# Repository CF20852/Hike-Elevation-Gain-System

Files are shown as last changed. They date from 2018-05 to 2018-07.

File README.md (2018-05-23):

# Hike Elevation Gain System

## :construction: Still! UNDER CONSTRUCTION :construction:
There's just another week's worth of work to do, and there always will be.
## Description
This tool uses a microcomputer connected to a GPS receiver and a barometric pressure sensor to record timestamped hike latitude, longitude, and both GPS and barometric elevation data, and a macro-enabled Excel workbook that processes the recorded data to calculate an accurate elevation gain value for a hike.  The workbook VBA macros can also generate a Keyhole Markup Language (.kml) file that can be used to plot the hike route using mapping software, and calculate the total distance of the hike and the distance from the start to various landmarks along the way.

I developed this tool mainly due to frustration with the wide range of elevation gains reported by various sources, including MapMyHike, Google Maps, Google Earth, and Global Mapper.  Google Maps and Google Earth seemed to report more elevation gain than MapMyHike, and Google Earth and Global Mapper (both of which use, or can be configured to use, the Shuttle Radar Topography Mission [SRTM] terrain elevation data) seemed to be in some agreement.

The tool is a system comprising a recording component and a processing component.  The recording component uses an [Arduino](https://www.arduino.cc/en/Guide/Introduction) (or [Arduino-like](http://wiki.microduinoinc.com/Microduino_Series)) hardware platform that incorporates a GPS receiver such as a u-Blox NEO-6M or NEO-M8N to measure and record GPS time, latitude, longitude, and elevation, and a Bosch BMP180/BMP280 temperature and pressure sensor to measure and record the barometric pressure.  For information on the Arduino platform, visit the [Arduino website](https://www.arduino.cc).  For information on the u-Blox GPS receivers, visit the [u-Blox Positioning Chips and Modules website](https://www.u-blox.com/en/positioning-chips-and-modules).  For information on the Bosch pressure sensors, visit the [Bosch Sensortec website](https://www.bosch-sensortec.com/bst/products/environmental/barometric_pressure_sensors/overview_barometricpressuresensors).

The processing component consists of a macro-enabled Excel workbook that processes the recorded data.  There are four main steps in the elevation data processing:
* Correcting the barometric altimeter data, using altimeter setting data from a local airport.  This is what aircraft pilots use to ensure that they have the correct altitude information for the local area;
* Further correcting the barometric altimeter data, using terrain elevation data, which helps remove any constant bias in the barometric elevation data;
* Filtering (smoothing) and plotting the elevation data; and 
* Computing hike elevation gain/loss statistics.

More specifically, processing the hike elevation data includes the following steps:
* Compute some basic statistics of the hike, which include:
  * Start and end time
  * Average latitude and longitude
* Get the Meteorological Terminal Aviation Routine Weather Report (METAR) data for the airport nearest the hike site from before the beginning of the hike until after the end of the hike, using an [API](https://www.aviationweather.gov/help/webservice?page=metarjson) from [NOAA's Aviation Weather Center](https://aviationweather.gov/metar) that returns data in JSON (JavaScript Object Notation) format.  This gives us the local barometric altimeter setting that aircraft pilots use to set their altimeters to indicate the correct altitude, regardless of the local barometric pressure (within reasonable limits).
* Interpolate the METAR altimeter setting data between METAR sample times for each hike data recording sample time.
* Use the interpolated altimeter setting data to correct the measured barometric-pressure-based elevation data.
* Get the Google Maps elevation data corresponding to the latitude/longitude coordinates, using a [Google Maps API](https://developers.google.com/maps/) that returns data in JSON format.  This gives us (I think) the SRTM elevation data.
* Further correct the recorded barometric elevation data by applying a 1st order correction based on the Google Maps elevation data, to correct any constant bias in the barometric pressure data.  This is done using the Excel Solver add-in to calculate a constant barometric pressure offset value that minimizes the sum of the squared differences between the barometric elevation value and the Google Maps elevation value at each hike data recording sample time.
* Filter the GPS, barometric, and Google Maps elevation data using an [infinite-impulse-response (IIR) filter](https://en.wikipedia.org/wiki/Infinite_impulse_response), the development of which has been facilitated by a [tool](http://www-users.cs.york.ac.uk/~fisher/mkfilter/trad.html) developed by Tony Fisher (who is, unfortunately, deceased).
* Compute and display the hike elevation gain and loss from GPS elevation, barometric elevation, and Google Maps elevation.
* Plot (graph) the data.

My initial findings, based on data from 4-5 hikes, are that the barometric elevation data (once calibrated) are probably more realistic and less "noisy" than the measured GPS elevation data and the Google Maps elevation data.  An additional finding, based on experiments with a counterfeit of a u-Blox NEO-6M receiver, is that some GPS receivers (such as the genuine u-Blox receiver) provide much more accurate results than others (such as the Chinese counterfeit of a u-Blox NEO-6M receiver apparently manufactured by Hangzhou ZhongKe Microelectronics CO., Ltd).

## Installation
### Arduino (like) Code
I've posted three versions of the Arduino (or Arduino-like) code.  These three versions are posted here as Arduino sketchbook (not sketch) folders.  All of them use [William Greiman's SdFat library, which can be obtained at this link](https://github.com/greiman/SdFat).  In addition, they use customized versions of [SlashDevin's NeoGPS library](https://github.com/SlashDevin/NeoGPS), which I placed in the libraries folder inside the Arduino sketchbook folder for each version:
    - A version that runs on a Microduino Core+ with the Microduino GPS, Motion, SD, and USBTTL modules, which requires you to install the Arduino for Microduino Integrated Development Environment (IDE) from [the Microduino download site](https://microduinoinc.com/download/).  This IDE includes libraries for the Microduino Motion (\_06_m_Module_Motion), module, which I use, and GPS module (\_06_m_Module_GPS), which I don't use, except for testing the hardware configuration.  For the GPS receiver, I use SlashDevin's NeoGPS library, with some customization in the header files.  Please refer to the NEO-6M Setup.docx document for explanation of the customization.  The Core+ gives you two hardware serial ports.
    - A version that runs on an Arduino Uno with a shield containing a Chinese counterfeit of a u-Blox NEO-6M GPS receiver, which does not implement the u-Blox protocol, and a microSD card socket, and an [Adafruit BMP280 Barometric Pressure + Temperature Sensor Breakout](https://learn.adafruit.com/adafruit-bmp280-barometric-pressure-plus-temperature-sensor-breakout) that I attached and wired onto the shield, connecting SDA on the BMP280 breakout to A4 (SDA) on the Arduino and SCL on the BMP280 breakout to A5 (SCL) on the Arduino.  For this version, I have used SlashDevin's NeoGPS library with some customization in the header files, and the Adafruit BMP280 library.  I found a Chinese-language protocol specification for the Chinese GPS module labeled as a u-blox NEO-6M at [Hangzhou Zhongke Microelectronics Co., Ltd.](http://www.icofchina.com/d/file/xiazai/2017-05-02/ea0cdd3d81eeebcc657b5dbca80925ee.pdf) and translated it to English (with some expected formatting issues) using an [online document translator](https://www.onlinedoctranslator.com/en/translate-chinese-(simplified)-to-english_zh-CN_en), which worked better than expected.  I put a copy of the translated document in the sketchbook folder for this version.  The Arduino Uno only gives you one hardware serial port, tied to the USB port, so this version uses SlashDevin's NeoSWSerial library to communicate with the GPS module.
    - A version that runs on an Arduino Uno with a [DuinoPeak shield](http://duinopeak.com/index.php?route=product/product&product_id=112) containing a u-Blox NEO-N8M GPS receiver and a microSD card socket, and an [Adafruit BMP280 Barometric Pressure + Temperature Sensor Breakout](https://learn.adafruit.com/adafruit-bmp280-barometric-pressure-plus-temperature-sensor-breakout) that I attached and wired onto the shield, connecting SDA on the BMP280 breakout to A4 (SDA) on the Arduino and SCL on the BMP280 breakout to A5 (SCL) on the Arduino.  I used SlashDevin's NeoGPS library with customized header files and the Adafruit BMP280 library for this version also.
1.  Configure your hardware according to one of the options above.
2.  Download the corresponding sketchbook folder.
3.  In the Arduino IDE, go to File... Preferences... Sketchbook location and set the sketchbook location to the location of the sketchbook folder corresponding to the hardware configuration you chose.  See the notes on Arduino library usage below for an explanation of why I do it this way.
4.  Compile and upload the sketch to your Arduino or Microduino.
#### Some notes on Arduino library usage
When I first started developing the three hardware variants of this project, I put all of the necessary libraries in C:\Users\username\My Documents\Arduino\libraries, where my sketchbook folder was C:\Users\username\My Documents\Arduino.  That was OK for the barometric pressure sensor, because I could use one library for the BMP180 and another library for the BMP280, with no customization required.  But the NeoGPS library is highly configurable via multiple header files for different protocol types (e.g., NMEA vs proprietary), variations on what NMEA sentences different receivers put out, and what information you want out of those sentences (e.g., if you don't need speed and heading, you can configure the library to not parse them, thus saving processing time and memory).  The NeoGPS library has a a src folder containing NMEA sentence processing .h and .cpp files, and subfolder under src called ublox, which contains .h and .cpp files for handling the u-blox proprietary GPS receiver protocol.  In addition, using an Arduino Uno, which only has one hardware serial port, you have a specific GPS serial port configuration, but with the Microduino Core+, you have a second hardware serial port that you can use, which requires a different GPSPort.h configuration in NeoGPS.  So I started out creating different versions of the various NeoGPS header files with different names for the different configurations.  This (IMO) was a really bad idea, because if I update the NeoGPS library, the Arduino library manager replaces the existing library folder with the updated library folder, thus wiping out any custom header files I created.  (Hooray for daily backups!)  Moreover, it starts to get ugly (inelegant) fast.

After some research, I learned that the Arduino IDE looks for libraries in several places (the following is Windows specific):  (1) the libraries folder in your sketchbook, e.g. C:\Users\username\My Documents\Arduino\libraries; (2) in the libraries folder of the Arduino IDE installation folder, e.g. C:\Program Files (x86)\Arduino\libraries; (3) in the folders below C:\Program Files (x86)\Arduino\hardware, e.g., C:\Program Files (x86)\Arduino\hardware\arduino\avr\libraries; and (4) in your sketch folder.  If you want to include a library in one of the first three places, you enclose the appropriate header file name in angle brackets (<>), e.g.,

`#include <SomeLib.h>`,

and if you want to include a library in your sketch (not sketchbook) folder, you enclose the header file name in double quotes, e.g.

`#include "MyLib.h"`.

I'm told that if you use the latter syntax, if the Arduino IDE doesn't find the library source file in your sketch folder, it will look in the places listed above for the angle bracket syntax.

To be able to have several different configurations of the NeoGPS library, as well as other libraries including Adafruit_BMP280_Library or Adafruit_BMP085_Library, NeoSWSerial (if using an Arduino Uno, not needed for a Microduino Core+), PString, and SDFat, the solution I eventually settled on is to have a different sketchbook folder for each configuration, containing a libraries folder and a sketch folder.  I have a copy of the each of the required libraries that are normally stored in the Arduino sketchbook folder in the libraries folder of the hardware-configuration-specific sketchbook folders.  The main disadvantage of this approach (in addition to multiple copies of libraries that you may need to update) is that you have to remember to point the Arduino IDE to the correct sketchbook.  You can easily change the sketchbook folder that the Arduino IDE uses under File... Preferences... Sketchbook location in the Arduino IDE (I'm using version 1.8.5 right now).

Another thing I learned is that if a library has at least one subfolder containing additional source code (.h and/or .cpp) files, all of the source code files must be within a src folder inside the library folder, or the IDE won't find the source code files within the subfolder.  An exception to this src folder requirement may be if the subfolder is named "utility".  See the Arduino IDE 1.5: Library specfication, under the Layout of folders and files heading.  I quote:  

>The source code found in src folder and all its subfolders is compiled and linked in the user's sketch. Only the src folder is added to the include search path (both when compiling the sketch and the library). When the user imports a library into their sketch (from the "Tools > Import Library" menu), an #include statement will be added for all header (.h) files in the src/ directory (but not its subfolders). As a result, these header files form something of a de facto interface to your library; in general, the only header files in the root src/ folder should be those that you want to expose to the user's sketch and plan to maintain compatibility with in future versions of the library. Place internal header files in a subfolder of the src/ folder.

>For backward compatibility with Arduino 1.0.x, the library author may opt to place source code into the root folder, instead of the folder called src. In this case the 1.0 library format is applied and the source code is searched from the library root folder and the utility folder...

I hope this explanation helps someone avoid wasting the amount of time I did in making my project work and look (I hope) at least a bit elegant.

### Excel Workbook
1.  Of course, you'll need Microsoft Excel to use the Excel macro-enabled workbook.  I used Excel 2016.

2.  I was very happy to find an Excel Visual Basic for Applications (VBA) JSON parser at https://github.com/VBA-tools/VBA-JSON.  It's always nice to find some giants who are willing to let you stand on their shoulders.  I just downloaded JsonConverter.bas from [that site](https://github.com/VBA-tools/VBA-JSON) and imported it into my Visual Basic code as a module.

3.  My Excel macro-enabled workbook also uses the Solver Add-in.  If you haven't already enabled it in your copy of Excel, you'll need to do so.  In my version (2016) of Excel, that's done by going to File... Options... Add-ins... Manage Excel Add-ins... Go, and then checking the Solver box and clicking OK.  Depending on which version of Excel you have, your approach may differ.

4.  Download and open the workbook from this page.  When you open the spreadsheet in Excel, you'll probably have to OK enabling macros.

5.  I hike mainly in Arizona, Maryland, Pennsylvania, Virginia, and West Virginia, so those are the states for which I've included airports that report METAR data in the Airports tab of the workbook.  If you live somewhere else, you'll need to download the airports for your area from the [ADDS Station Table](https://www.aviationweather.gov/docs/metar/stations.txt).  Only include the stations that have a "X" in the "M" column of the table (column 63).  Just append them to the bottom of the Airports sheet below the other airports.

## Operation
### Arduino
There's not much to it.  The way it stands right now, if you plug a [well-formatted SD card](https://www.sdcard.org/downloads/formatter_4/) into the recorder, with less than 99 HikeLgxx.csv files (where xx = 0-99) on it, and apply power, it'll create a new HikeLgxx.csv file with the next available number and start recording every 2 seconds as soon as the GPS receiver starts outputting messages.
### Excel Workbook
#### Elevation Gain Calculations
This is a lot more complicated than the Arduino part, given the current state of the "art"...
1.  Ensure that you have an internet connection, because the macros have to retrieve data using the Aviation Weather Center METAR API and the Google Maps elevation data API;
2.  On the Control sheet of the Excel workbook, enter the following data:
    - Your Google Maps API key, which you can obtain from [this website](https://developers.google.com/maps/documentation/elevation/start), in cell B7;
    - Date of the hike, in YYYY-MM-DD or MM/DD/YYYY format, in cell B14.
    - As far as the other cells on the Control sheet are concerned, you should either not mess with them or they will be automagically filled in by the macros.
2.  Open the .csv file recorded by the Microduino or Arduino as an Excel spreadsheet;
3.  Delete everything in the Data sheet of the Excel workbook below the header row, which is row 1 i.e., delete everything in row 2 and below;
4.  Copy the UTC time, latitude and longitude (+/-DD.DDDDD format), GPS elevation (feet), temperature (degrees C), pressure (HPa), baro elevation (feet), number of satellites, HDOP, and VDOP data from the appropriate Hikelgxx.csv file to the Data sheet starting in Row 2, Column 1, i.e. starting in cell A2 of the Data worksheet;
5.  Press \<CTRL>\<p>  to start processing the data.
6.  Look at the results on the Data sheet, primarily in Row 2, Columns U, Y, and AC.  Also look at the two charts, Unfilt Elev and Filt Elev, to get a sense of how the three data sources (GPS elevation, baro elevation, and Google Maps elevation) match up.
#### KML File Generation
This is somewhat simpler than the elevation gain calculations:
1.  On the Control sheet of the Excel workbook, enter the file location at which you want to store your .kml file, should you choose to generate one, in cells B1-B3;
2.  Press \<CTRL>\<k> to generate the .kml file.
#### Distance Calculations
##### Total Hike Distance Calculation
Press \<CTRL>\<d> to calculate the total distance of the hike.
##### Distance to a Waypoint or Landmark
1. Enter the latitude and longitude of the waypoint in cells B27 and C27 respectively;
2. Press \<CTRL>\<q> to calculate the distance.

##  Brief Description of the Excel Workbook
### Control Tab
This is the worksheet on which you enter some parameters related to generating a Keyhole Markup Language (.kml) file, your Google Maps API keyt, the date of the hike, waypoint latitude and longitude if you want to calculate distance to a waypoint.  It's also where certain intermediate results of the elevation processing show up, and where the distances are displayed.
### Data Tab
This is the worksheet onto which you copy and paste the data from the hike log file recorded by the Arduino (like) machine.
### Airports Tab
This is the worksheet that contains the information (most importantly, the latitude and longitude) of any airports from which you want the workbook to retrieve local altimeter setting data.
### METARS Tab
This is a worksheet whose contents are automatically generated by the macros after retrieving the METAR data for the selected airport.
### GM API Rqsts Tab
This is a worksheet whose contents are automatically generated by the macros in the process of requesting elevation data from Google Maps.
### GM Elev Tab
This is a worksheet whose contents are automatically generated by the macros from the elevation data returned by the Google Maps API.
### Unfilt Elev Chart
This is an automatically generated chart showing the unfiltered barometric, GPS, and Google Maps elevation data versus UTC time.
### Filt Elev Chart
This is an automatically generated chart showing the filtered barometric, GPS, and Google Maps elevation data versus UTC time.  The filter is a digital third-order Butterworth IIR filter implemented in a macro.
### Filt Elev v Dist Chart
This is an automatically generated chart showing the filtered barometric, GPS, and Google Maps elevation data versus distance from the beginning of the hike.  The filter is a digital third-order Butterworth IIR filter implemented in a macro.

## Some initial results
This figure shows the GPS altitude (blue) and barometric cabin pressure (orange) of a flight from Phoenix, Arizona to Baltimore, Maryland, just plotted straight from the recorded .csv file:

PHX-BWI

This figure shows the GPS altitude and corrected barometric elevation measured at a stationary location next to a sliding glass door in my basement, processed through the Excel workbook:

Basement

This figure shows the filtered GPS, barometric, and Google Maps elevations with respect to distance from the beginning of a hike from where the Appalachian Trail crosses State Rte 94 south of Mount Holly Springs, Pennsylvania to Boiling Springs, Pennsylvania.  This used a u-blox NEO-M8N GNSS receiver, which I think I accidently left in AIR_4G dynamics mode, instead of PEDESTRIAN mode:

AT Hike 20 May 2018

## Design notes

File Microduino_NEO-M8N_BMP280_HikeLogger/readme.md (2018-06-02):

This version is for a Microduino with an Arduino Uno adapter including the Core+ module and the DuinoPeak NEO-M8N + SD shield with an Adafruit BMP280 breakout attached.

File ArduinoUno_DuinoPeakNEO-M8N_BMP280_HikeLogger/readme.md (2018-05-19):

This version is for the Arduino Uno with a shield containing a u-blox NEO-M8N, a Bosch BMP-280, and a microSD card socket.

If you buy a NEO-M8N/microSD shield from DuinoPeak, the NEO-M8N may come with firmware version 2.01.  If so, you may have to upgrade the firmware to version 3.01 for this configuration to work properly.  (Try it without upgrading the NEO-M8N firmware first.)  You can upgrade the firmware using the u-blox u-connect software, which I obtained from https://www.u-blox.com/en/evaluation-software-and-tools for my Windows 10 laptop.  Use the u-blox 8/M8 Firmware v 3.01 - ONLY for Standard Precision NGSS products, which I obtained at https://www.u-blox.com/sites/default/files/UBX_M8_301_SPG.911f2b77b649eb90f4be14ce56717b49.bin .

One of the benefits of upgrading is that you could configure the NEO-M8N to simultaneously use GPS, Galileo, and GLONASS or Galileo, GLONASS, and BeiDou signals.  See section 32.11.11 of the u-blox 8/ u-blox M8 Receiver Description Including Protocol Specification document (Document number UBX-13003221) to learn how to compose the necessary u-blox command.  I haven't included that in this sketch, due to the fact that running on an Arduino Uno, the sketch already consumes perilous amounts of flash and RAM.  The default configuration of the u-blox 8/u-blox M8 Standard Precision GNSS modules using both firmware versions 2.01 and 3.01 is to use GPS, SBAS, QZSS, and GLONASS signals.  See Appendix B.6, GNSS System Settings, of Document number UBX-13003221.  See Appendix A of that document for how u-blox numbers the GNSS system types 0-6, corresponding to GPS, SBAS, Galileo, BeiDou, IMES, QZSS, and GLONASS respectively.

In order to connect u-center running on my laptop to the NEO-M8N on the DuinoPeak shield, I used an Arduino Uno and configured the DuinoPeak shield to communicate with the Arduino Uno using D0 and D1, rather than D2 and D3.  I found trying to relay the serial port through the Arduino Uno software to be too unreliable.  I wrote a small sketch to configure D0 and D1 as inputs for this purpose, using the Arduino pinMode() function.

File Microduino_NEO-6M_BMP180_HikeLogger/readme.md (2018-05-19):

This version is for a Microduino board stack including the Core+, USBTTL, SD, GPS, and Motion modules.  The GPS module includes a genuine u-blox NEO-6M and the Motion module includes a Bosch BMP-180.

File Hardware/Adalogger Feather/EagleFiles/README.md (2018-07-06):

Autodesk Eagle 9.0.1 (free version) files for a Feather daughterboard for an Adafruit Feather M0 Adalogger.

There is at least one error in this design:  the GPIOSDA and GPIOSCL lines coming from the Adafruit Adalogger board do not have pullup resistors, and because these lines are open-drain, the daughterboard must provide the pullup resistors.

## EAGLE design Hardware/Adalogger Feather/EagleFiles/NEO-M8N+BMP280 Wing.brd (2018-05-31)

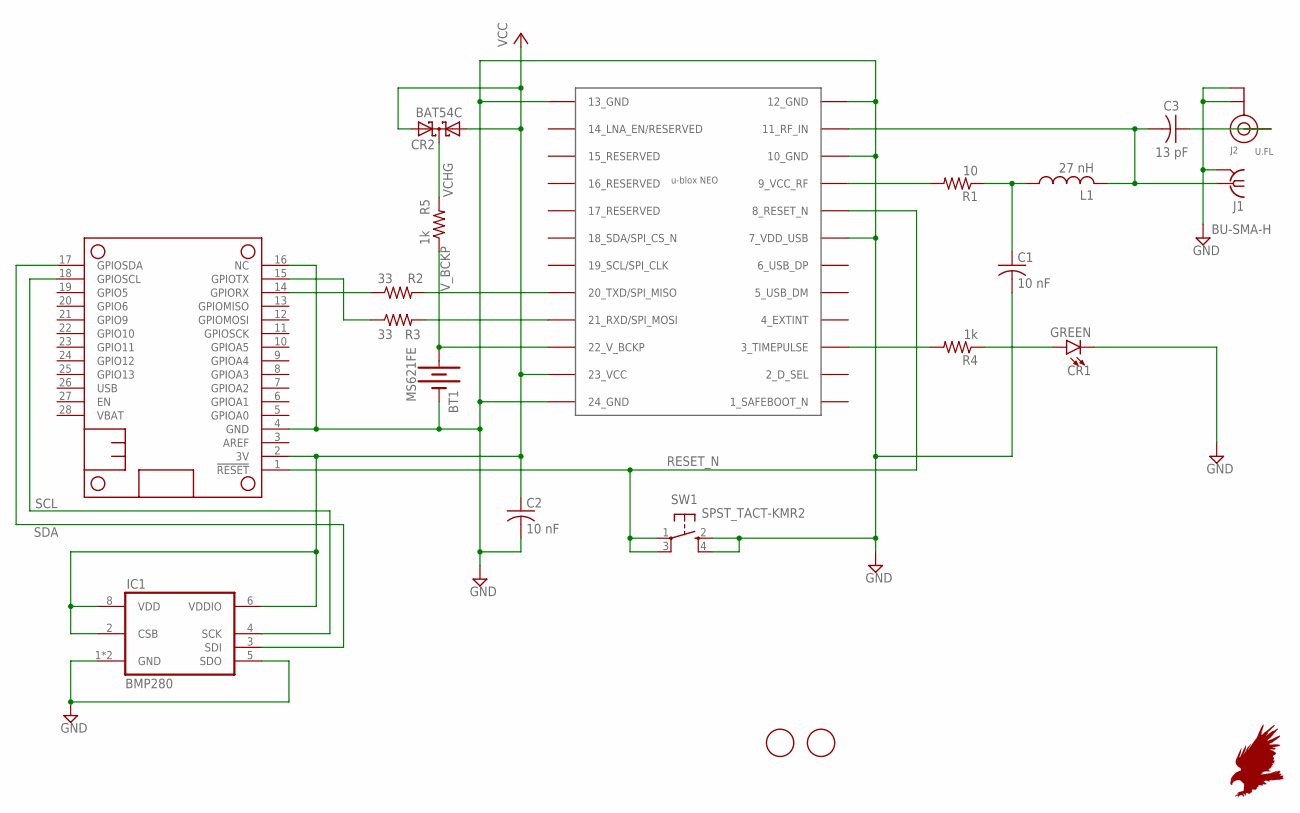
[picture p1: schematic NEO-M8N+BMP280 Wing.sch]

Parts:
BT1: MS621FE; BATTCON-6.8MM
C1, C2: 10 nF; C0402
C3: 13 pF; C0402
CR1: GREEN; LED-0603
CR2: BAT54C; SOT23
FID1, FID2: FIDUCIAL; FIDUCIAL_1MM
IC1: BMP280
J1: BU-SMA-H
J2: U.FL
L1: 27 nH; L0402
MS1: FEATHERWING
R1: 10; R0805
R2, R3: 33; R0805
R4, R5: 1k; R0805
SW1: SPST_TACT-KMR2; KMR2
U$2: NEO-M8

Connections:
FEATHER_RXD: MS1.14 (GPIORX), R2.1
FEATHER_TXD: MS1.15 (GPIOTX), R3.1
GND: BT1.-, C1.2, C2.2, CR1.C, IC1.1 (GND), IC1.5 (SDO), IC1.7 (GND), J1.2, J1.3 (2), J1.4 (2), J1.5 (2), J2.1 (GND), J2.2 (GND), MS1.4 (GND), MS1.16 (NC), SW1.2 (S), SW1.4 (S1), U$2.7 (7_VDD_USB), U$2.10 (10_GND), U$2.12 (12_GND), U$2.13 (13_GND), U$2.24 (24_GND)
GPS_RXD: R3.2, U$2.21 (21_RXD/SPI_MOSI)
GPS_TXD: R2.2, U$2.20 (20_TXD/SPI_MISO)
J2_RF: C3.1, J2.3 (SIGNAL)
LED_ANODE: CR1.A, R4.1
LNA_BIAS: C1.1, L1.P$1 (1), R1.1
RESET_N: MS1.1 (!RESET), SW1.1, SW1.3 (P1), U$2.8 (8_RESET_N)
RF_IN: C3.2, J1.1, L1.P$2 (2), U$2.11 (11_RF_IN)
SCL: IC1.4 (SCK), MS1.18 (GPIOSCL)
SDA: IC1.3 (SDI), MS1.17 (GPIOSDA)
TP: R4.2, U$2.3 (3_TIMEPULSE)
VCC: C2.1, CR2.1 (A1), CR2.2 (A2), IC1.2 (CSB), IC1.6 (VDDIO), IC1.8 (VDD), MS1.2 (3V), U$2.23 (23_VCC)
VCC_RF: R1.2, U$2.9 (9_VCC_RF)
VCHG: CR2.3 (CC), R5.2
V_BCKP: BT1.+, R5.1, U$2.22 (22_V_BCKP)

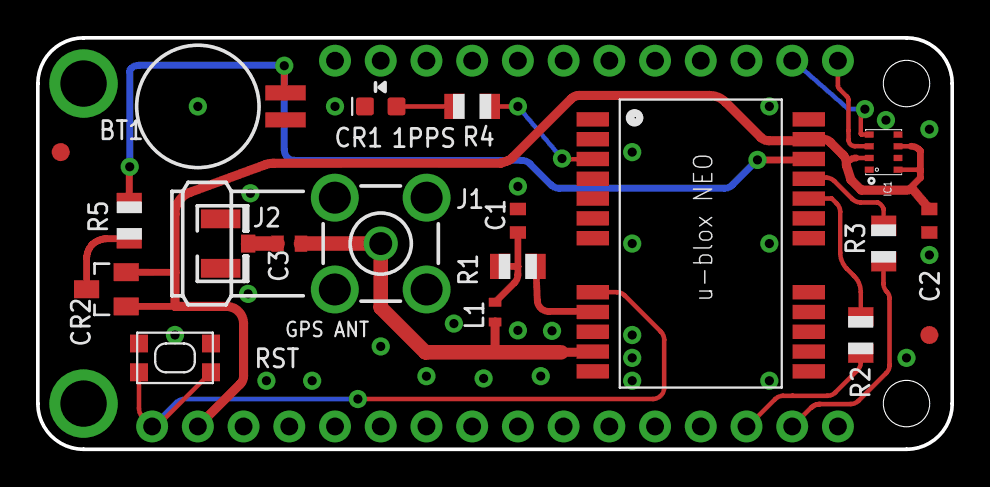
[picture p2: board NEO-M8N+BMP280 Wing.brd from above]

Board: 2 copper layers, 50.8 x 22.9 mm, 20 parts (0 on the bottom side), 17 nets.

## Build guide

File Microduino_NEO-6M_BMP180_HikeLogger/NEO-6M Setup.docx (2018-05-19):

The following is from Appendix A of the u-Blox 6 Receiver Description including Protocol Specification. Default configuration parameters highlighted in yellow should be changed for the hike logging application. Changes are explained at the end of this document.

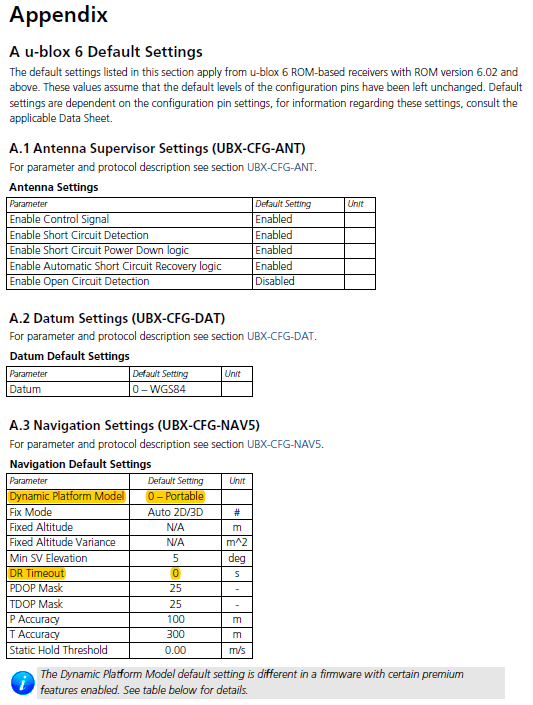
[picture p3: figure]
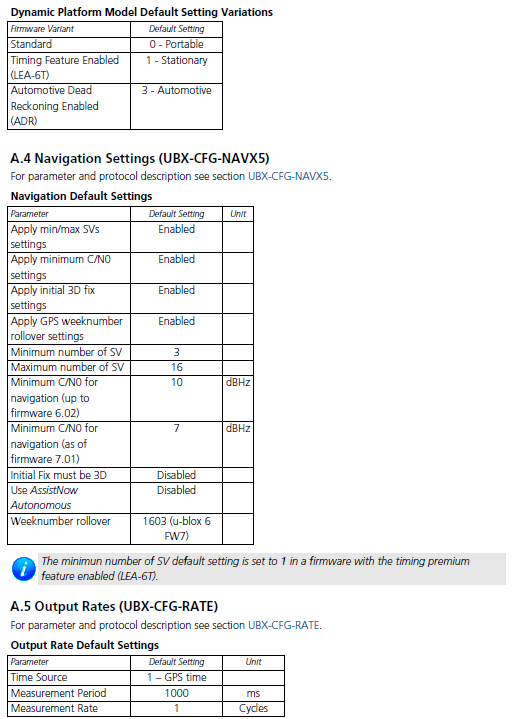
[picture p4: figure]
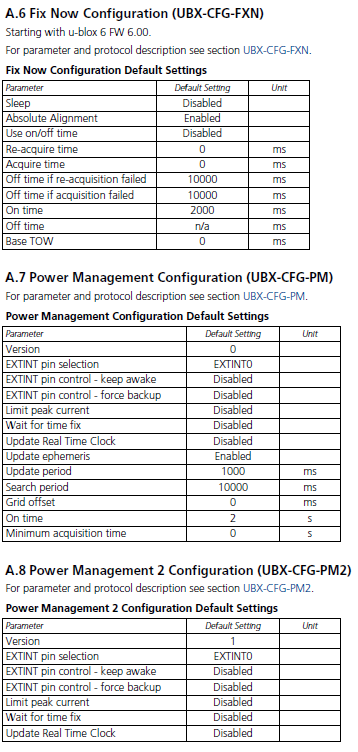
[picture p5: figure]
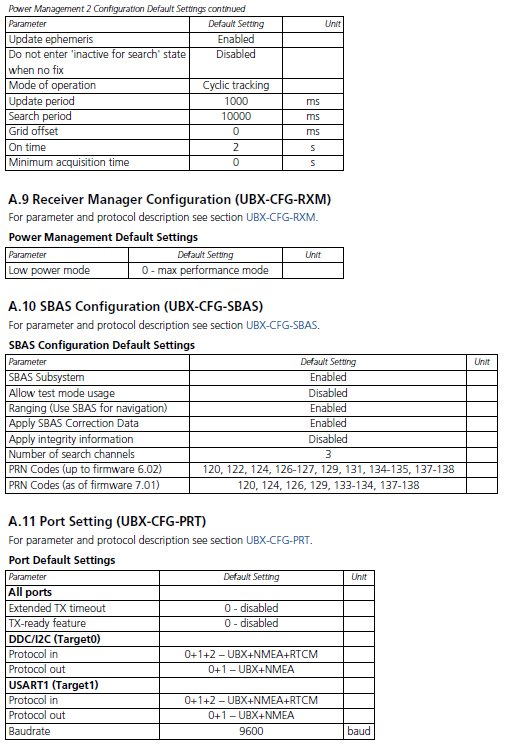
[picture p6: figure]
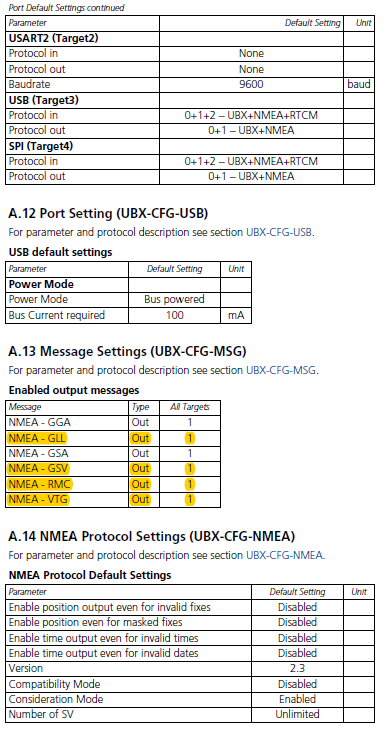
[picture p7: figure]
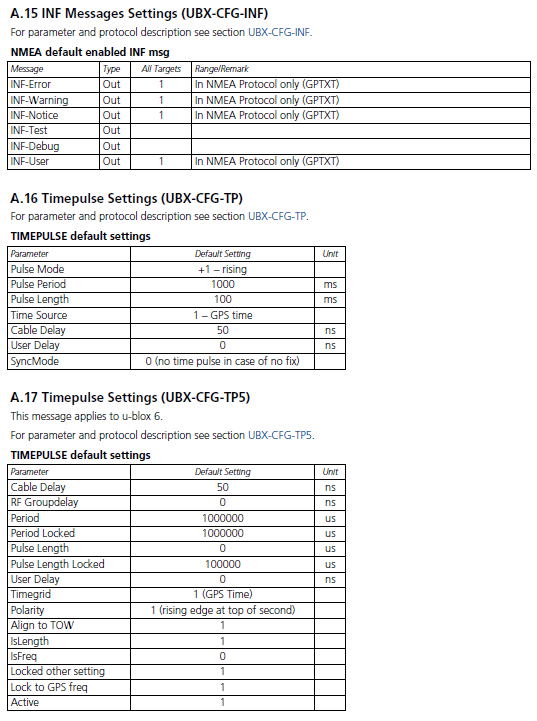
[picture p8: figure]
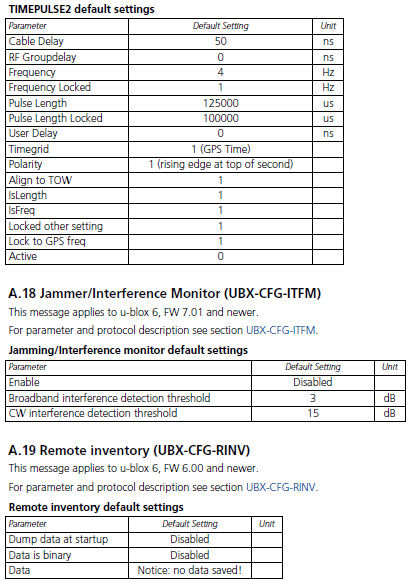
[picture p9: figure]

Default Navigation Settings (UBX-CFG-NAV5)

For parameter and protocol description see section UBX-CFG-NAV5.
Parameter | Default Setting | Desired Setting | Unit
Dynamic Platform Model | 0 – Portable | 3 -- Pedestrian
Fix Mode | Auto 2D/3D | Auto 2D/3D | #
Fixed Altitude | N/A | N/A | m
Fixed Altitude Variance | N/A | N/A | m^2
Min SV Elevation | 5 | 5 | deg
DR Timeout | 0 | 30 | s
PDOP Mask | 25 | 25 | -
TDOP Mask | 25 | 25 | -
P Accuracy | 100 | 100 | m
T Accuracy | 300 | 300 | m
Static Hold Threshold | 0 | 0 | m/s

Code to change NAV5 settings using NeoGPS library by SlashDevin:

Brute force method:

ublox::cfg_nav5_t setNav;

setNav.apply_word = 0x0009; // only change dynModel and drLimit

setNav.dyn_model = ublox::UBX_DYN_MODEL_PEDESTRIAN;

setNav.fix_mode = ublox::UBX_POS_FIX_AUTO;

setNav.fixed_alt = 0; // m

setNav.fixed_alt_variance = 10000; // 10000 * m^2

setNav.min_elev = 5; // degrees

setNav.dr_limit = 20; // s

setNav.pos_dop_mask = 250; // 10 * DOP

setNav.time_dop_mask = 250; // 10 * DOP

setNav.pos_acc_mask = 100; // m

setNav.time_acc_mask = 300; // s (although spec says "m")

setNav.static_hold_thr = 0; // cm/s

setNav.dgps_timeout = 0; // s

More readable and precise method:

// THIS COMMAND SETS THE NAV5 MODES using the more readable and precise method

ublox::cfg_nav5_t navCfg;

// set the mask bit indicating we're changing the dynamic model...

navCfg.apply.dyn_model = true

// and change the model to Pedestrian, for hikers

// note that UBX_DYN_MODEL_AIR_4G was tested on an airline flight (PHX-BWI) and works

navCfg.dyn_model = ublox::UBX_DYN_MODEL_PEDESTRIAN;

// set the mask bit indicating we're changing the ded(uced) reckoning limit...

// and change the limit to 20 s, for hikers whose signals are sometimes blocked

navCfg.apply.dr_limit = true;

navCfg.dr_limit = 20;

while (!gps.send( navCfg )) {

DEBUG_PORT.print( '.' );

delay( 500 );

}

Message Settings (UBX-CFG-MSG)

For parameter and protocol description see section UBX-CFG-MSG.
Message | Default Targets & Rate | Desired Targets & Rate
NMEA - GGA | All, 1 | UART 1, 1
NMEA - GLL | All, 1 | None
NMEA - GSA | All, 1 | UART 1, 1
NMEA - GSV | All, 1 | None
NMEA - RMC | All, 1 | None
NMEA - VTG | All, 1 | None

Code to change message settings using NeoGPS library by SlashDevin:

NMEAGPS::nmea_msg_t msgType[6] =

{NMEAGPS::NMEA_GGA, NMEAGPS::NMEA_GLL, NMEAGPS::NMEA_GSA, NMEAGPS::NMEA_GSV, NMEAGPS::NMEA_RMC, NMEAGPS::NMEA_VTG};

uint8_t rate[6] = {1, 0, 1, 0, 0, 0};

int maxI = (sizeof(msgType)/sizeof(NMEAGPS::nmea_msg_t));

for (int i = 0; i < maxI; i++) {

Serial.print(F("Setting message type "));

Serial.print(msgType[i]);

Serial.print(F(" to rate "));

Serial.println(rate[i]);

while (!ublox::configNMEA(gps, msgType[i], rate[i])) {

Serial.print( '.' );

delay( 500 );

}

Serial.println();

}

Also, in NMEAGPS_cfg.h of SlashDevin’s NeoGPS library, make sure NMEAGPS_PARSE_SATELLITES, NMEAGPS_PARSE_GGA, NMEAGPS_PARSE_GSA, NMEAGPS_COMMA_NEEDED, and LAST_SENTENCE_IN_INTERVAL NMEAGPS::NMEA_GSA are #defined, consistent with the message types enabled by the code above.

In GPSfix_cfg.h of SlashDevin’s NeoGPS library, comment/uncomment the #defines as shown below:

//#define GPS_FIX_DATE

#define GPS_FIX_TIME

#define GPS_FIX_LOCATION

//#define GPS_FIX_LOCATION_DMS

#define GPS_FIX_ALTITUDE

//define GPS_FIX_SPEED

//#define GPS_FIX_VELNED

//define GPS_FIX_HEADING

#define GPS_FIX_SATELLITES

#define GPS_FIX_HDOP

#define GPS_FIX_VDOP

//#define GPS_FIX_PDOP

//#define GPS_FIX_LAT_ERR

//#define GPS_FIX_LON_ERR

//#define GPS_FIX_ALT_ERR

//#define GPS_FIX_GEOID_HEIGHT

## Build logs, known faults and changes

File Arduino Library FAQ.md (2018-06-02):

# Arduino Library FAQ
## Where does the Arduino IDE look for libraries?
The Arduino IDE looks for libraries in several places (the following is Windows specific):  (1) the libraries folder in your sketchbook, e.g. C:\Users\username\My Documents\Arduino\libraries; (2) in the libraries folder of the Arduino IDE installation folder, e.g. C:\Program Files (x86)\Arduino\libraries; (3) in the folders below C:\Program Files (x86)\Arduino\hardware, e.g., C:\Program Files (x86)\Arduino\hardware\arduino\avr\libraries; and (4) in your sketch folder.  If you want to include a library in one of the first three places, you *should* enclose the appropriate header file name in angle brackets (<>), e.g.,

`#include <SomeLib.h>`, 

and if you want to include a library in your sketch (not sketchbook) folder, or in a library folder inside a src folder in your sketch folder, you *must* enclose the header file name in double quotes, e.g.

`#include "MyLib.h"` or<br>
`#include "src/MyLib1/src/MyLib1.h"`.

Note that if you use the double-quote syntax, the Arduino IDE will also look in the places listed above for the angle brackets syntax if it doesn't find the source files in your sketch folder.

## What do I do if I need multiple versions of the same library, or a customized version?
First, some cautionary advice:  The Arduino IDE will generate advisory (not error, or warning) messages if it finds multiple, identically-named copies of the same header files in the locations in which it searches for libraries.  This should tell you to think carefully about what you've done.  

Moreover, and more importantly, if you update the library using the Arduino Library Manager, the new library folder will replace the existing library folder with the same name in your sketchbook folder.  If you update a library using the Arduino Library Manager while the Arduino IDE sketchbook folder is set to your specific sketchbook location, the library in your specific sketchbook location will be overwritten. In the interest of caution and at the cost of repetition, I'll re-emphasize this point below.

Four options you can consider are:

1.  Under this option, your libraries are assumed to be in the default library location, which under Windows, is C:\Users\username\My Documents\Arduino\libraries.  If there are a small number of source code (i.e., .h and .cpp) files in the library, you can assign different file names to different versions of the source code files.  *If you choose this option, be sure to back up your custom source code files if you decide to update the library.  If you update a library using the Arduino Library Manager while the Arduino IDE sketchbook folder is set to the default sketchbook location, the library in the default sketchbook location will be overwritten.*
2.  If there are many source code files in the library, it might be better to place your sketch and the custom libraries it requires, along with any other libraries your sketch requires that are normally located in the default sketchbook folder, in a separate sketchbook folder.  You can tell the Arduino IDE to use that sketchbook folder by going to File... Preferences... Sketchbook location in the Arduino IDE and setting the sketchbook location to the appropriate folder.  You should maintain the structure of the original library folder(s), including maintaining the source code in a subfolder of your library folder(s) called "src".  You may also need to tailor the example sketches for your customized libraries according to your own needs, in which case the place to do it is within the examples folder of your library folder(s).  *Be aware that if you update a library using the Arduino Library Manager while the Arduino IDE sketchbook folder is set to your specific sketchbook location, the library in your specific sketchbook location will be overwritten.*  The sketchbook structure should end up looking something like this, assuming you have a folder in the root directory of your C: drive called Arduino Sketchbooks:
<br>C:
<br>&emsp;|_Arduino Sketchbooks
<br>&emsp;&emsp;|_MySketchbook1
<br>&emsp;&emsp;&emsp;|_MySketch1
<br>&emsp;&emsp;&emsp;&emsp;|_MySketch1.ino
<br>&emsp;&emsp;&emsp;&emsp;|_libraries
<br>&emsp;&emsp;&emsp;&emsp;&emsp;|_MyLibrary1
<br>&emsp;&emsp;&emsp;&emsp;&emsp;&emsp;|_src
<br>&emsp;&emsp;&emsp;&emsp;&emsp;&emsp;&emsp;|_lib1.h
<br>&emsp;&emsp;&emsp;&emsp;&emsp;&emsp;&emsp;|_lib1.cpp
<br>&emsp;&emsp;&emsp;&emsp;&emsp;|_MyLibrary2
<br>&emsp;&emsp;&emsp;&emsp;&emsp;&emsp;|_src
<br>&emsp;&emsp;&emsp;&emsp;&emsp;&emsp;&emsp;|_lib2.h
<br>&emsp;&emsp;&emsp;&emsp;&emsp;&emsp;&emsp;|_lib2.cpp

The next two approaches were suggested by per1234:

3.  Rather than dealing with multiple sketchbooks, another way to handle the different versions of a library is to bundle a modified version of that library with each sketch. So the sketch directory tree would look like this:
<br>C:
<br>&emsp;|_Arduino Sketchbooks
<br>&emsp;&emsp;|_MySketch1
<br>&emsp;&emsp;&emsp;|_MySketch1.ino
<br>&emsp;&emsp;&emsp;|_src
<br>&emsp;&emsp;&emsp;&emsp;|_MyLibrary1
<br>&emsp;&emsp;&emsp;&emsp;&emsp;|_src
<br>&emsp;&emsp;&emsp;&emsp;&emsp;&emsp;|_lib1.h
<br>&emsp;&emsp;&emsp;&emsp;&emsp;&emsp;|_lib1.cpp
<br>&emsp;&emsp;&emsp;&emsp;|_MyLibrary2
<br>&emsp;&emsp;&emsp;&emsp;&emsp;|_src
<br>&emsp;&emsp;&emsp;&emsp;&emsp;&emsp;|_lib2.h
<br>&emsp;&emsp;&emsp;&emsp;&emsp;&emsp;|_lib2.cpp

And the sketch includes the libraries like this:
    
    #include "src/MyLibrary1/src/lib1.h"
    #include "src/MyLibrary2/src/lib2.h"

Then the sketches can all share the other libraries that don't require any modifications.

4.  Another option is to make each version of each library for which you need a hardware-specific variation a separate library in the main libraries folder (e.g., C:\Users\username\My Documents\Arduino\libraries) with a separate name. If you change the folder name then there is no problem with Library Manager updates overwriting the modified library. If you change the header file name then you will be able to control which library is included by your code. The advantage of this is that it would permit you to merge all of your sketch variations into one. The you can have a configuration macro at the top of the sketch:

`// Uncomment one of the following lines to configure the sketch:`<br>
`// #define HARDWARE_CONFIGURATION_1`<br>
`// #define HARDWARE_CONFIGURATION_2`<br>
`// #define HARDWARE_CONFIGURATION_3`<br>

Then anywhere there is code that differs between the versions:

    #if defined(HARDWARE_CONFIGURATION_1)
    // HARDWARE_CONFIGURATION_1 specific code here
    #elif defined(HARDWARE_CONFIGURATION_2)
    // HARDWARE_CONFIGURATION_2 specific code here
    #else
    // HARDWARE_CONFIGURATION_3 specific code here
    #endif

This is a good option if you have a lot of code that's shared between the various n sketches, otherwise when you want to make a change it get's really tiresome having to do it nX every time. The disadvantage is all that preprocessor code gets pretty messy.

## What do I do if I need to create my own library?
Even if you don't plan to publish your library for use by others, you should follow the [Arduino Library Specification](https://github.com/arduino/Arduino/wiki/Arduino-IDE-1.5:-Library-specification).  If you aren't going to publish your library, you don't need the library.properties file or the keywords.txt file, nor do you need to have an examples folder or an extras folder.

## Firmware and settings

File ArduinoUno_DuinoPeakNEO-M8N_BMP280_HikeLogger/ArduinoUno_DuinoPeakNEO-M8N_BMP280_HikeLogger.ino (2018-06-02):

/*
  SD card datalogger

  This example shows how to log data from a u-Blox NEO-6M GPS receiver and BMP280 barometric altimeter to an SD card.

  created  24 Nov 2010
  modified 9 Apr 2012
  by Tom Igoe

  adapted for GPS and BMP180 14-30 Apr 2018
  by Chip Fleming

  This code is developed for the Wanderbirds hiking club.
*/

#define recordingInterval 2  //seconds between successive samples

//#define SERIALPORT
#undef SERIALPORT

#include <PString.h>

char buffer[80];
PString dataString(buffer, sizeof(buffer));

// BEGIN SD CARD SECTION *****************************************************************************
#include <SPI.h>
#include "SdFat.h"

// SD chip select pin.  Be sure to disable any other SPI devices such as Enet.
const uint8_t chipSelect = 8;

// Log file base name.  Must be six characters or less.
#define FILE_BASE_NAME "HikeLg"

// File system object.
SdFat sd;

// Log file.
SdFile file;

#define error(msg) sd.errorHalt(F(msg))
// END SD CARD SECTION *******************************************************************************

// BEGIN GPS SECTION *********************************************************************************
//In NMEAGPS_cfg.h of SlashDevin’s NeoGPS library, make sure NMEAGPS_PARSE_SATELLITES, NMEAGPS_PARSE_GGA,
//NMEAGPS_PARSE_GSA, NMEAGPS_COMMA_NEEDED, and LAST_SENTENCE_IN_INTERVAL NMEAGPS::NMEA_TXT are #defined.
//The other NMEAGPS_PARSE_XXX should not be defined, because those messages sent by the NEO-M8N
//do not provide any information that we need and GGA and GSA do not provide.

//In GPSfix_cfg.h of SlashDevin’s NeoGPS library, #define some parameters and comment out the definitions of others, as follows:
//#define GPS_FIX_DATE
//#define GPS_FIX_TIME
//#define GPS_FIX_LOCATION
////#define GPS_FIX_LOCATION_DMS
//#define GPS_FIX_ALTITUDE
////define GPS_FIX_SPEED
////#define GPS_FIX_VELNED
////define GPS_FIX_HEADING
//#define GPS_FIX_SATELLITES
//#define GPS_FIX_HDOP
//#define GPS_FIX_VDOP
////#define GPS_FIX_PDOP
////#define GPS_FIX_LAT_ERR
////#define GPS_FIX_LON_ERR
////#define GPS_FIX_ALT_ERR
////#define GPS_FIX_GEOID_HEIGHT

#include <NMEAGPS.h>
#include <ublox/ubxGPS.h>

#include <GPSport.h>
#include <Streamers.h>

static ubloxGPS gps( &gpsPort );

static NMEAGPS  nmeaGPS; // This parses the GPS characters
gps_fix  fix; // This holds on to the latest values

// END GPS SECTION ***********************************************************************************

// BEGIN BMP280 SECTION ******************************************************************************
#include <Wire.h>
#include "Adafruit_BMP280.h"

Adafruit_BMP280 bmp;
// END BMP280 SECTION ********************************************************************************

void sendUBX( const unsigned char *progmemBytes, size_t len )
//This sends a u-blox-formatted command to the NEO-M8N GPS module, and computes and appends the checksum.
{
  //write the SYNC word
  gpsPort.write( 0xB5 ); // SYNC1
  gpsPort.write( 0x62 ); // SYNC2

  //write the payload, which is in program memory and update the checksum
  uint8_t a = 0, b = 0;
  while (len-- > 0) {
    uint8_t c = pgm_read_byte( progmemBytes++ );
    a += c;
    b += a;
    gpsPort.write( c );
  }

  //write the checksum
  gpsPort.write( a ); // CHECKSUM A
  gpsPort.write( b ); // CHECKSUM B

} // sendUBX

const unsigned char ubxSetUART138400[] PROGMEM =
{ 0x06, 0x00, 0x14, 0x00, 0x01, 0x00, 0x00, 0x00, 0xC0, 0x08, 0x00, 0x00, 0x00, 0x96, 0x00, 0x00, 0x07, 0x00, 0x03, 0x00, 0x00, 0x00, 0x00, 0x00 };

void setup() {
  // Open serial communications and wait for port to open:
  DEBUG_PORT.begin(115200);
  while (!Serial)
    ;
  DEBUG_PORT.println(F("Starting up SD card, NEO-M8N, and BMP280....."));

#if defined (SERIALPORT)
  DEBUG_PORT.println(F("Initializing log file name and SD card..."));
#endif
  // BEGIN SD CARD SECTION *****************************************************************************
  // set up file name
  const uint8_t BASE_NAME_SIZE = sizeof(FILE_BASE_NAME) - 1;
  char fileName[13] = FILE_BASE_NAME "00.csv";

  // Initialize at the highest speed supported by the board that is
  // not over 50 MHz. Try a lower speed if SPI errors occur.
  if (!sd.begin(chipSelect, SD_SCK_MHZ(50))) {
    sd.initErrorHalt();
  }

  // Find an unused file name.
  if (BASE_NAME_SIZE > 6) {
    error("FILE_BASE_NAME too long");
  }
  while (sd.exists(fileName)) {
    if (fileName[BASE_NAME_SIZE + 1] != '9') {
      fileName[BASE_NAME_SIZE + 1]++;
    } else if (fileName[BASE_NAME_SIZE] != '9') {
      fileName[BASE_NAME_SIZE + 1] = '0';
      fileName[BASE_NAME_SIZE]++;
    } else {
      error("Can't create file name");
    }
  }
  if (!file.open(fileName, O_CREAT | O_WRITE | O_EXCL)) {
    error("file.open");
  }
  else {
    DEBUG_PORT.print(fileName);
    DEBUG_PORT.println(F(" opened OK"));
  }
  // END SD CARD SECTION *******************************************************************************

  // BEGIN GPS SECTION *********************************************************************************
  //start the GPS module port at 9600 bps, which is the default for the u-blox NEO-M8N
  gpsPort.begin(9600);
  delay(1000);

  //tell the NEO-M8N to switch to 38.4 kbps
  sendUBX( ubxSetUART138400, sizeof(ubxSetUART138400) );
  delay(1000);

  //restart the Arduino GPS port at 38.4 kbps
  gpsPort.begin(38400);

  //Turn on NMEA messages GxGGA, GxGSA, GxRMC (which we only need for the date, once) and turn everything else off
  NMEAGPS::nmea_msg_t msgType[6] =
  {NMEAGPS::NMEA_GGA, NMEAGPS::NMEA_GLL, NMEAGPS::NMEA_GSA, NMEAGPS::NMEA_GSV, NMEAGPS::NMEA_RMC, NMEAGPS::NMEA_VTG};
  uint8_t rate[6] = {1, 0, 1, 0, 1, 0};

  int maxI = (sizeof(msgType) / sizeof(NMEAGPS::nmea_msg_t));

  for (int i = 0; i < maxI; i++) {
    DEBUG_PORT.print(F("Setting message type "));
    DEBUG_PORT.print(msgType[i]);
    DEBUG_PORT.print(F(" to rate "));
    DEBUG_PORT.print(rate[i]);
    while (!ublox::configNMEA(gps, msgType[i], rate[i])) {
      DEBUG_PORT.print( '.' );
      delay( 500 );
    }
    DEBUG_PORT.println();
  }

  DEBUG_PORT.println("Completed setting the Msg Mode!");
  DEBUG_PORT.println();


  //  THIS COMMAND SETS THE NAV5 MODES using the more readable and precise method
  ublox::cfg_nav5_t navCfg;
  navCfg.apply.dyn_model = true;                       // set the mask bit indicating we're changing the dynamic model...
  navCfg.dyn_model = ublox::UBX_DYN_MODEL_PEDESTRIAN;  //and change the model to Pedestrian, for hikers
  //
  //  // the following two lines should be commented out for the NEO-M8N, for which the ded(uced) reckoning mode is reserved
  //  navCfg.apply.dr_limit = true;                        // set the mask bit indicating we're changing the ded reckoning limit...
  //  navCfg.dr_limit = 20;                                //and change the limit to 20 s, for hikers whose signals are sometimes blocked
  //
  DEBUG_PORT.print( F("Setting uBlox nav mode") );
  while (!gps.send( navCfg )) {
    DEBUG_PORT.print( '.' );
    delay( 500 );
  }
  DEBUG_PORT.println();
  DEBUG_PORT.println("Completed setting the Nav Mode!");
  DEBUG_PORT.println();
  //

  // END GPS SECTION ***********************************************************************************

  // BEGIN BMP280 SECTION ******************************************************************************
  //see if we can start the BMP280
  if (!bmp.begin()) {
    DEBUG_PORT.println(F("Could not find a valid BMP280 sensor, check wiring!"));
  }
  else {
    DEBUG_PORT.println(F("Found a BMP280 sensor, setup is complete."));
  }
  // END BMP280 SECTION ********************************************************************************
}  // end of setup()

uint8_t lastGPSSeconds = 0;
uint32_t timer = millis();
float BMP280Temperature, BMP280Pressure, BMP280Altitude;
bool fileDateSet = false;

void loop() {

  BMP280Temperature = 0;
  BMP280Pressure = 0;
  BMP280Altitude = 0;

  // read data from the GPS in the 'main loop'
  while (nmeaGPS.available( gpsPort )) {
    fix = nmeaGPS.read();
    //DEBUG_PORT.print(".");
  }

  // if the inter-sample interval has elapsed, (optionally) display and record the GPS time,
  //
  if ((fix.dateTime.seconds % recordingInterval == 0) && (fix.dateTime.seconds != lastGPSSeconds) && (fix.latitude() != 0.0)) {
    lastGPSSeconds = fix.dateTime.seconds;

    // if we have valid GPS date and time and we haven't set the file timestamp, do so now
    if ( (!fileDateSet) && (fix.valid.date) && (fix.valid.time) ) {
      if (!file.timestamp(T_CREATE | T_WRITE | T_ACCESS, (uint16_t)fix.dateTime.year + 2000, fix.dateTime.month, fix.dateTime.day,
                                                                   fix.dateTime.hours, fix.dateTime.minutes, fix.dateTime.seconds)) {
        error("set file date failed");
      }
      else {
        DEBUG_PORT.println(F("file timestamped OK"));
        fileDateSet = true;
      }
    }
    
    // clear the dataString
    dataString.begin();

    //print some readable GPS info, if we're debugging
#if defined SERIALPORT
    Serial.println();

    DEBUG_PORT.print( F("Location: ") );
    if (fix.valid.location) {
      DEBUG_PORT.print( fix.latitude(), 6 );
      DEBUG_PORT.print( ", " );
      DEBUG_PORT.print( fix.longitude(), 6 );
    }

    DEBUG_PORT.print( F(", Altitude: ") );
    if (fix.valid.altitude)
      DEBUG_PORT.print( fix.altitude_ft() );

    DEBUG_PORT.print( F(", Satellites: ") );
    if (fix.valid.satellites)
      DEBUG_PORT.print( fix.satellites );

    DEBUG_PORT.print( F(", HDOP: ") );
    if (fix.valid.hdop)
      DEBUG_PORT.print( fix.hdop );

    DEBUG_PORT.print( F(", VDOP: ") );
    if (fix.valid.vdop)
      DEBUG_PORT.print( fix.vdop );

    DEBUG_PORT.println();
#endif

    //add the GPS fix info to the csv data string to be stored on the microSD card
    dataString.print(fix.dateTime.hours, DEC);
    dataString.print(F(":"));
    dataString.print(fix.dateTime.minutes, DEC);
    dataString.print(F(":"));
    dataString.print(fix.dateTime.seconds, DEC);
    dataString.print(F(", "));

    dataString.print(fix.latitude(), 6);
    dataString.print(F(", "));
    dataString.print(fix.longitude(), 6);
    dataString.print(F(", "));
    dataString.print(fix.altitude() * 3.28084, 1);
    dataString.print(F(", "));

    dataString.print(fix.satellites);
    dataString.print(F(", "));
    dataString.print(fix.hdop / 1000.0);
    dataString.print(F(", "));
    dataString.print(fix.vdop / 1000.0);
    dataString.print(F(", "));

    BMP280Temperature = bmp.readTemperature();
    BMP280Pressure = bmp.readPressure();
    BMP280Altitude = bmp.readAltitude(1013.25);

    //print readable BMP280 measurements, if we're debugging
#if defined (SERIALPORT)
    DEBUG_PORT.print(F("Temperature = "));
    DEBUG_PORT.print(BMP280Temperature);
    DEBUG_PORT.println(F(" *C"));

    DEBUG_PORT.print(F("Pressure = "));
    DEBUG_PORT.print(BMP280Pressure);
    DEBUG_PORT.println(F(" Pa"));

    DEBUG_PORT.print(F("Altitude = "));
    DEBUG_PORT.print(BMP280Altitude * 3.28084);
    DEBUG_PORT.println(F(" feet"));
#endif

    //add the BMP280 sensor info to the csv data string to be stored on the microSD card
    dataString.print(BMP280Temperature, 1);
    dataString.print(F(", "));
    dataString.print(BMP280Pressure, 1);
    dataString.print(F(", "));
    dataString.print(BMP280Altitude * 3.28084, 1);

    //write the data string to the microSD card
    file.println(dataString);

    // Force data to SD and update the directory entry to avoid data loss.
    if (!file.sync() || file.getWriteError()) {
#if defined (SERIALPORT)
      error("write error");
#endif
    }

    // print to the serial port too:
    //#if defined (SERIALPORT)
    DEBUG_PORT.println(dataString);
    //#endif
  } // end if

}  // end of loop()

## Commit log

2018-05-19 Create Arduino Library FAQ.md
2018-05-19 Update Arduino Library FAQ.md

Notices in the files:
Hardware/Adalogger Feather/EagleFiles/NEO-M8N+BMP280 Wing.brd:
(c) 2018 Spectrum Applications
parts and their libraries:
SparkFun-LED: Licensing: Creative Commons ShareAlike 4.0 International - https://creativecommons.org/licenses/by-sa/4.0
